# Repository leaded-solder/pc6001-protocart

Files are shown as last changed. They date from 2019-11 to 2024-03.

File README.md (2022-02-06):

# PC-6001 Cartridge Protoboard
Simple layout for a prototyping board for constructing NEC PC-6001 cartridges.

# Version History
 * v0.6 (Feb. 2022): Improved ground pours and silkscreens to ease assembly.
 * v0.5: First working version

# Special Thanks
 * alank2 on the Vintage Computer Festival forum, for measuring his Canyon Climber cartridge

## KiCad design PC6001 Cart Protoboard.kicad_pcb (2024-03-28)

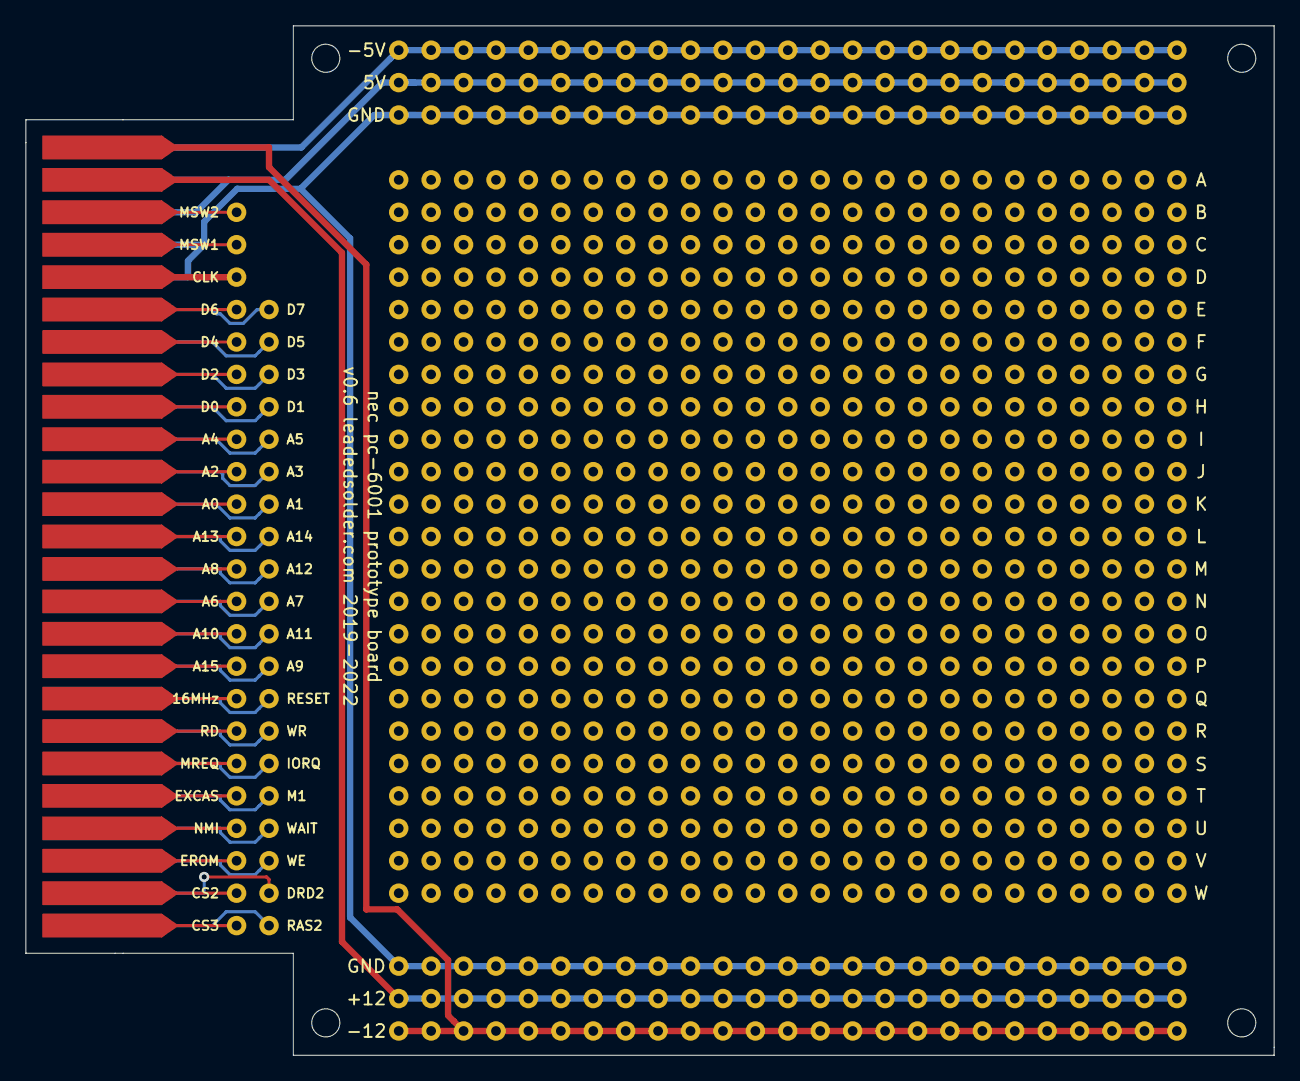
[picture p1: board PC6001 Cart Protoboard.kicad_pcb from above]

Board: 2 copper layers, 97.8 x 80.6 mm, 50 parts (0 on the bottom side), 48 nets.

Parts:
5V: TestPoint; Strip_25
16MHz: TestPoint; Proto_1
+12: TestPoint; Strip_25
-5V, -12: TestPoint; Strip_25
A0, A2, A4, A6, A8, A10, A13, A15: TestPoint; Proto_1
A1, A3, A5, A7, A9, A11, A12, A14: TestPoint; Proto_1_Odd
CLK: TestPoint; Proto_1
CS2, CS3: TestPoint; Proto_1
D0, D2, D4, D6: TestPoint; Proto_1
D1, D3, D5, D7: TestPoint; Proto_1_Odd
DRD2: TestPoint; Proto_1_Odd
EROM: TestPoint; Proto_1
EXCAS: TestPoint; Proto_1
GND: TestPoint; Strip_25
GND#2: TestPoint; Strip_25
IORQ: TestPoint; Proto_1_Odd
J1: Conn_02x25_Odd_Even; PC6001 Cartridge Connector
M1: TestPoint; Proto_1_Odd
MREQ: TestPoint; Proto_1
MSW1, MSW2: TestPoint; Proto_1
NMI: TestPoint; Proto_1
RAS2: TestPoint; Proto_1_Odd
RD: TestPoint; Proto_1
RESET: TestPoint; Proto_1_Odd
WAIT: TestPoint; Proto_1_Odd
WE: TestPoint; Proto_1_Odd
WR: TestPoint; Proto_1_Odd

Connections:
/5V: 5V.1, J1.45, J1.47
/12V: +12.1, J1.48
/-5V: -5V.1, J1.49
/-12V: -12.1, J1.50
/A0: A0.1, J1.28
/A1: A1.1, J1.27
/A2: A2.1, J1.30
/A3: A3.1, J1.29
/A4: A4.1, J1.32
/A5: A5.1, J1.31
/A6: A6.1, J1.22
/A7: A7.1, J1.21
/A8: A8.1, J1.24
/A9: A9.1, J1.17
/A10: A10.1, J1.20
/A11: A11.1, J1.19
/A12: A12.1, J1.23
/A13: A13.1, J1.26
/A14: A14.1, J1.25
/A15: A15.1, J1.18
/CLK: CLK.1, J1.42
/CLK-16M: 16MHz.1, J1.16
/CS2: CS2.1, J1.4
/CS3: CS3.1, J1.2
/D0: D0.1, J1.34
/D1: D1.1, J1.33
/D2: D2.1, J1.36
/D3: D3.1, J1.35
/D4: D4.1, J1.38
/D5: D5.1, J1.37
/D6: D6.1, J1.40
/D7: D7.1, J1.39
/DRD2: DRD2.1, J1.3
/EROM: EROM.1, J1.6
/EXCAS: EXCAS.1, J1.10
/GND: GND.1, GND#2.1, J1.41, J1.43
/IORQ: IORQ.1, J1.11
/M1: J1.9, M1.1
/MREQ: J1.12, MREQ.1
/MSW1: J1.44, MSW1.1
/MSW2: J1.46, MSW2.1
/NMI: J1.8, NMI.1
/RAS2: J1.1, RAS2.1
/RD: J1.14, RD.1
/RESET: J1.15, RESET.1
/WAIT: J1.7, WAIT.1
/WE: J1.5, WE.1
/WR: J1.13, WR.1

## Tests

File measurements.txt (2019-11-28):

NEC PC-6001 Canyon Climber Cartridge

width 3.296"
length 4.320"
thickness 0.797"

pcb width 2.870"
pcb length 3.559" (no fingers)
pcb length 4.031" (with fingers)
pcb thickness 0.065" (1.6mm)
pcb fingers width 2.571 (65.3mm)

fingers pitch 0.100" (2.54mm)
fingers width 0.070" (1.78mm)
fingers thickness pcb only (no metal fingers) .059" (1.5mm)
fingers thickness with fingers on both sides measured 0.066 - each finger may be 0.0035" thick.

there is one hole that lines up with the cartridge case - it is in the middle of the width (1.435" from each edge of pcb).
hole is 0.323" diameter
hole is also 0.880" from edge of fingers to its center.

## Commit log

2019-11-27 Custom footprint
    [PC6001 Cart Protoboard.kicad_pcb, PC6001 Cart Protoboard.sch]
2019-11-27 Got an edge
    [PC6001 Cart Protoboard.kicad_pcb]
2019-11-27 Revise layout with new footprint
    [PC6001 Cart Protoboard.kicad_pcb]
2019-11-27 10mm fingers
    [PC6001 Cart Protoboard.kicad_pcb]
2019-11-27 25-pin power bus
    [PC6001 Cart Protoboard.kicad_pcb, PC6001 Cart Protoboard.sch]
2019-11-27 Probably have to re-think the power planes again
    [PC6001 Cart Protoboard.kicad_pcb, PC6001 Cart Protoboard.sch]
2019-11-27 Working my way through the pins now
    [PC6001 Cart Protoboard.kicad_pcb, PC6001 Cart Protoboard.sch]
2019-11-27 the board outline
    [PC6001 Cart Protoboard.kicad_pcb]
2019-11-27 All pins routed, waiting for strips
    [PC6001 Cart Protoboard.kicad_pcb, PC6001 Cart Protoboard.sch]
2019-11-27 Strips added
    [PC6001 Cart Protoboard.kicad_pcb]
2019-11-27 plot config
    [PC6001 Cart Protoboard.kicad_pcb]
2019-11-27 v0.2 - 25 pin
    [PC6001 Cart Protoboard.kicad_pcb, PC6001 Cart Protoboard.sch]
2019-11-27 Shorty version
    [PC6001 Cart Protoboard.kicad_pcb]
2019-11-28 PCB finger width increased to 1.77mm
    [PC6001 Cart Protoboard.kicad_pcb]
2019-11-28 Edge width is now correct
    [PC6001 Cart Protoboard.kicad_pcb]
2019-12-16 Fix it so the pads actually aren't masked
    [PC6001 Cart Protoboard.kicad_pcb]
2019-12-23 Shortened pads to provide 1.25mm keepout
    [PC6001 Cart Protoboard.kicad_pcb]
2022-02-06 Improve solder mask removal
    [PC6001 Cart Protoboard.kicad_pcb]
2024-03-28 KiCad 7
    [PC6001 Cart Protoboard.kicad_pcb, PC6001 Cart Protoboard.kicad_sch, PC6001 Cart Protoboard.sch]
